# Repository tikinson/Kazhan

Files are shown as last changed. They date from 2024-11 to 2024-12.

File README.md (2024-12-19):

# 🦇Kazhan🦇

projectlogo

28 Keys. MX and Choc compatible keyboard with CH552T controller. This is the next logical step after my experimental keyboard [ToadsTempest](https://github.com/tikinson/ToadsTempest).

## Idea

Kazhan (Кажан) is derived from the Ukrainian word meaning "bat".
As a fan of ZilpZalp/Hummingbird projects i decided make something with same layout but more personalized. Same but different.

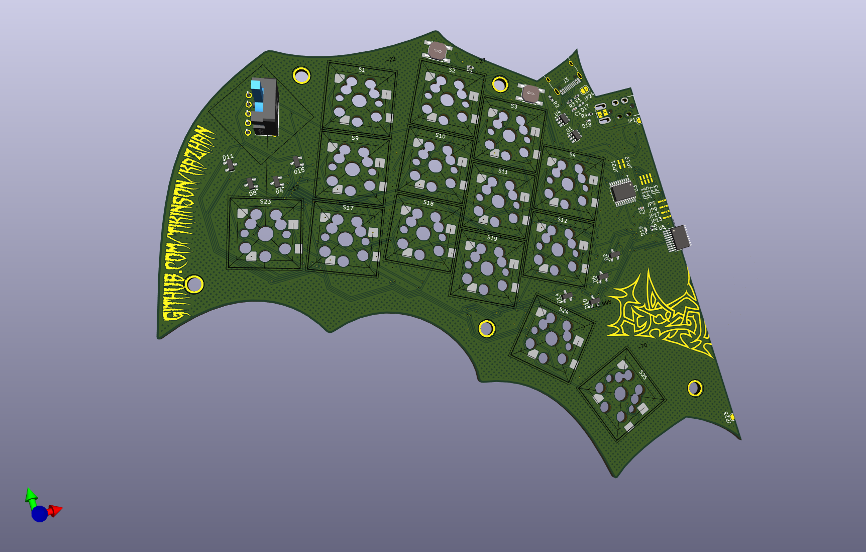
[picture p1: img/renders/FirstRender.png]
first_render


## What this project is and what it is not

### Goals:
- A pet project of a keyboard as an act of absolute self-expression.
- Flexibility and experiments over (and maybe in some case against) minimalistic design approach.
- Testing interesting "non - conventional" switches as extra keys.
- Testing things that i don't saw (yet?) in another keyboard PCB designs.

### Non-goals:
- Creation of another variant of the Corne (I like Corne btw, that was my first love in this hobby).
- Design with a definite assembly variant.
- Go through the steps in the keyboard design that I have already tried.

## Features

- Mirrored design of PCB to provide split and unibody functionality in one design.
- Alpsalpine limit switches (SW1, SW2 on schematics) as additional switches. I accidentaly understood, that MX keycap kinda fits on them (with 45 dergee rotation), so i would give them a try.
- Wired USB-C (USB 2.0) connection.
- Designed for usage with [really affordable chip](https://www.lcsc.com/product-detail/USB-ICs_WCH-Jiangsu-Qin-Heng-CH552T_C111367.html) and [F.A.K.](https://github.com/semickolon/fak?tab=readme-ov-file) firmware.
- Japanese (duplex) matrix of keys and diodes for them: first of all, it's way more easy to solder one dual diode instead of two regular, because you will never put this part with wrond polarity. And also because of type of key matrix, there is two types of dual diodes: with common anode and common cathode.

## Layout

## BOM

Opening local copy of [ibom.html](./bom/ibom.html) could save some times while soldering.

| Reference | Value | Footprint | Qty | LCSC |
|---|---|---|-----|---|
| C1, C2 | 100nF | Capacitor_SMD:C_0402_1005Metric_Pad0.74x0.62mm_HandSolder  | 2 | C1525 |
| D1, D4, D5, D8, D9, D11, D13, D15 | BAS70-06-CAnode | Package_TO_SOT_SMD:SOT-23 | 8 | C8651 |
| D2, D3, D6, D7, D10, D12, D14, D16 | BAS70-05-CCatode  | Package_TO_SOT_SMD:SOT-23 | 8 | C34489 |
| D17 | PMEG2010EA | Diode_SMD:D_0402_1005Metric_Pad0.77x0.64mm_HandSolder | 1 | C2837790  |
| D18, D19 | PWR LED | LED_SMD:LED_0402_1005Metric | 2 | C130724 |
| F1 | 500mA | Fuse:Fuse_0402_1005Metric_Pad0.77x0.64mm_HandSolder | 1 | C210357 |
| J3 | USB_C_Receptacle_USB2.0 | Connector_USB:USB_C_Receptacle_HRO_TYPE-C-31-M-12 | 1 | C2765186  |
| R1, R6 | 10k | Resistor_SMD:R_0402_1005Metric_Pad0.72x0.64mm_HandSolder | 2 | C25744 |
| R2, R3 | 5.1k | Resistor_SMD:R_0402_1005Metric_Pad0.72x0.64mm_HandSolder | 2 | C25905 |
| R4, R5 | 1k | Resistor_SMD:R_0402_1005Metric | 2 | C11702 |
| SW1, SW2 | ~ | MyFootprintsCollection:SW-TH_SSCF110100 | 2 | C470322 |
| SW4, SW6 | RESET | KEY-SMD_4P-L4.8-W4.8-P3.70-LS6.4-TL | 2 | C2888968  |
| S1–S28 | Keyswitch | SW_Hotswap_Kailh_Choc_MX_1.00u_One_Sided | 28  | |
| U1, U4 | USBLC6-2SC6 | Package_TO_SOT_SMD:SOT-23-6 | 2 | C2687116  |
| U2, U3, U5 | CH552T | -- mixed footprints -- | 3 | C111367 |

#### Note: S1-S28 - is footprints for switches. You can choose between MX or Kailh Choc switches (or both if you like experiments) and solder hotswaps accordingly.

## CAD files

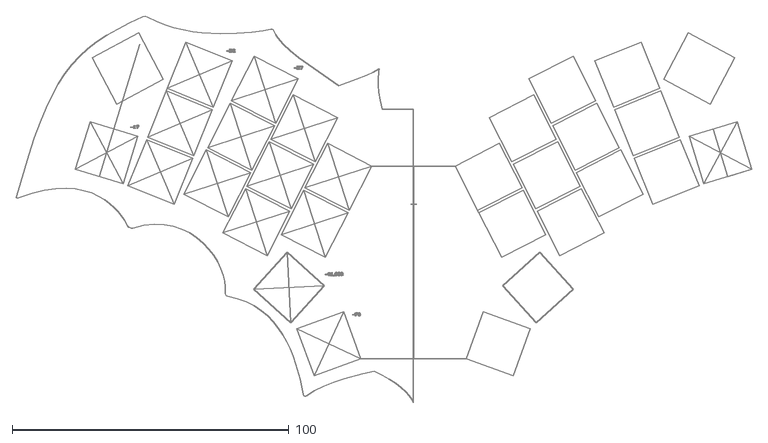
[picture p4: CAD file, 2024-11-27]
img/kazhanSecond.dxf
265.8 x 139.6

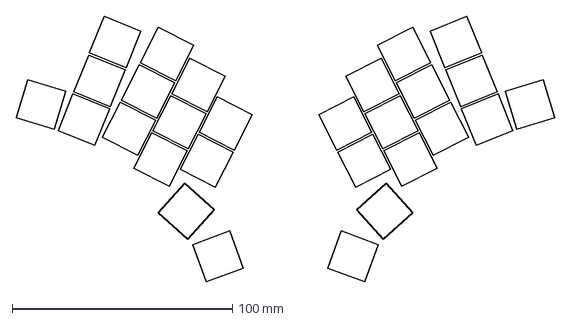
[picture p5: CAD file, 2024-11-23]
img/renders/demo.dxf
244.5 x 120.6 mm

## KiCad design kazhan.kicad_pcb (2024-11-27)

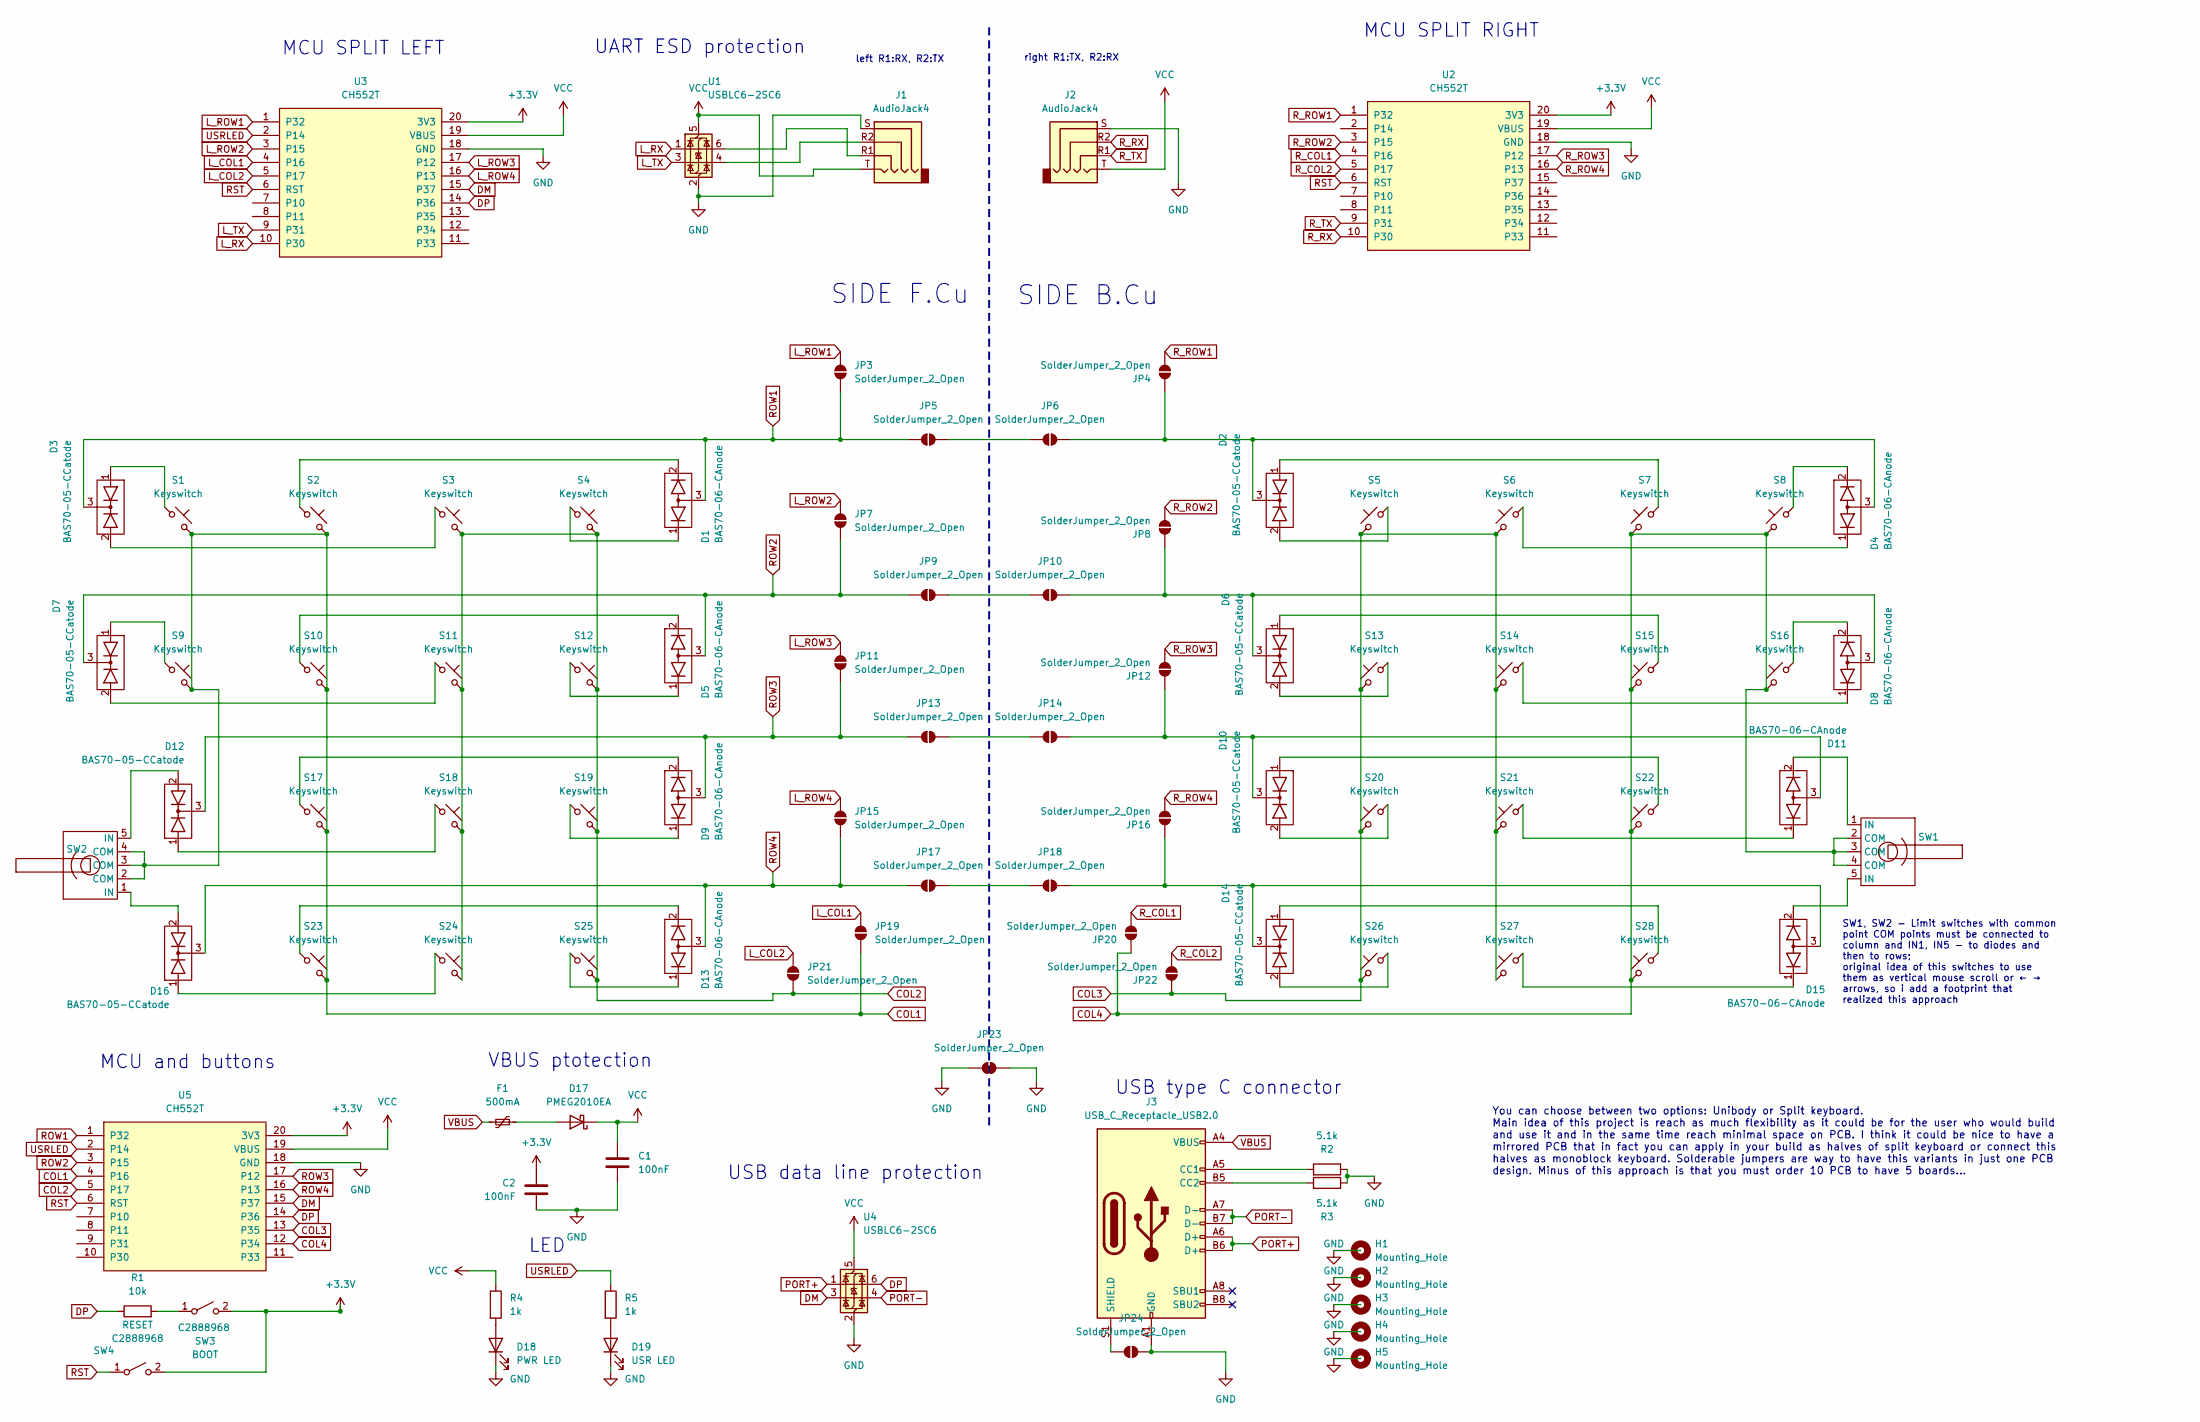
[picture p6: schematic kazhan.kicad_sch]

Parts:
C1, C2: 100nF; C_0402_1005Metric_Pad0.74x0.62mm_HandSolder; LCSC C1525
D1, D4, D5, D8, D9, D11, D13, D15: BAS70-06-CAnode; SOT-23
D2, D3, D6, D7, D10, D12, D14, D16: BAS70-05-CCatode; SOT-23
D17: PMEG2010EA; D_0402_1005Metric_Pad0.77x0.64mm_HandSolder; LCSC C2837790
D18: PWR LED; LED_0402_1005Metric; LCSC C130724
D19: USR LED; LED_0402_1005Metric; LCSC C130724
F1: 500mA; Fuse_0402_1005Metric_Pad0.77x0.64mm_HandSolder; LCSC C210357
H1, H2, H3, H4, H5: Mounting_Hole; MountingHole_3.5mmX4.5mm_Pad
J1: AudioJack4; PJ-320A-REVERSIBLE-F.Cu-placing
J2: AudioJack4; PJ-320A-REVERSIBLE-B.Cu-placing
J3: USB_C_Receptacle_USB2.0; USB_C_Receptacle_HRO_TYPE-C-31-M-12; JLCPCB_CORRECTION 0; -1.35; 0
JP3, JP4, JP7, JP8, JP11, JP12, JP15, JP16, JP19, JP20, JP21, JP22, JP24: SolderJumper_2_Open; SolderJumper-2_P1.3mm_Open_RoundedPad1.0x1.5mm
JP5, JP9, JP13, JP17: SolderJumper_2_Open; SolderJumper-EdgeCut-F.Cu-Placing
JP6, JP10, JP14, JP18: SolderJumper_2_Open; SolderJumper-EdgeCut-B.Cu-Placing
JP23: SolderJumper_2_Open; SolderJumper-F.Cu-B.Cu
R1: 10k; R_0402_1005Metric_Pad0.72x0.64mm_HandSolder; LCSC C25744
R2, R3: 5.1k; R_0402_1005Metric_Pad0.72x0.64mm_HandSolder; LCSC C25905
R4, R5: 1k; R_0402_1005Metric; LCSC C11702
S1, S2, S3, S4, S5, S6, S7, S8, S9, S10, S11, S12, S13, S14, S15, S16, S17, S18, S19, S20, S21, S22, S23, S24, S25, S26, S27, S28: Keyswitch; SW_Hotswap_Kailh_Choc_MX_1.00u_One_Sided
SW1, SW2: SW-TH_SSCF110100
SW3: BOOT; KEY-SMD_4P-L4.8-W4.8-P3.70-LS6.4-TL; LCSC C115357
SW4: RESET; KEY-SMD_4P-L4.8-W4.8-P3.70-LS6.4-TL; LCSC C115357
U1, U4: USBLC6-2SC6; SOT-23-6; JLCPCB_CORRECTION 0; 0; 270
U2, U3: CH552T; TSSOP-20_4.4x6.5mm_P0.65mm; LCSC C111367
U5: CH552T; TSSOP-20_4.4x6.5mm_P0.65mm-REVERSIBLE; LCSC C111367

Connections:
+3.3V: C2.1, SW3.2 (B), SW4.2 (B), U2.20 (3V3), U3.20 (3V3), U5.20 (3V3)
COL1: JP19.1 (A), S1.2, S2.2, S9.2, S10.2, S17.2, S23.2, SW2.2 (COM), SW2.3 (COM), SW2.4 (COM), U5.4 (P16)
COL2: JP21.1 (A), S3.2, S4.2, S11.2, S12.2, S18.2, S19.2, S24.2, S25.2, U5.5 (P17)
COL3: JP22.2 (B), S5.2, S6.2, S13.2, S14.2, S20.2, S21.2, S26.2, S27.2, U5.13 (P35)
COL4: JP20.2 (B), S7.2, S8.2, S15.2, S16.2, S22.2, S28.2, SW1.2 (COM), SW1.3 (COM), SW1.4 (COM), U5.12 (P34)
DM: U3.15 (P37), U4.3 (I/O2), U5.15 (P37)
DP: R1.1, U3.14 (P36), U4.6 (I/O1), U5.14 (P36)
GND: C1.2, C2.2, D18.1 (K), D19.1 (K), J1.S, J2.S, J3.A1 (GND), J3.A12 (GND), J3.B1 (GND), J3.B12 (GND), JP23.1 (A), JP23.2 (B), JP24.2 (B), R2.1, R3.1, U1.2 (GND), U2.18 (GND), U3.18 (GND), U4.2 (GND), U5.18 (GND); also elsewhere on the board
L_COL1: JP19.2 (B), U3.4 (P16)
L_COL2: JP21.2 (B), U3.5 (P17)
L_ROW1: JP3.2 (B), U3.1 (P32)
L_ROW2: JP7.1 (A), U3.3 (P15)
L_ROW3: JP11.1 (A), U3.17 (P12)
L_ROW4: JP15.1 (A), U3.16 (P13)
L_RX: U1.1 (I/O1), U3.10 (P30)
L_TX: U1.3 (I/O2), U3.9 (P31)
unnamed: D1.1 (A), S4.1
unnamed: D1.2 (A), S2.1
unnamed: D2.1 (A), S7.1
unnamed: D2.2 (A), S5.1
unnamed: D2.3 (K), D4.3 (K), JP4.1 (A), JP6.2 (B)
unnamed: D3.1 (A), S1.1
unnamed: D3.2 (A), S3.1
unnamed: D4.1 (A), S6.1
unnamed: D4.2 (A), S8.1
unnamed: D5.1 (A), S12.1
unnamed: D5.2 (A), S10.1
unnamed: D6.1 (A), S15.1
unnamed: D6.2 (A), S13.1
unnamed: D6.3 (K), D8.3 (K), JP8.1 (A), JP10.2 (B)
unnamed: D7.1 (A), S9.1
unnamed: D7.2 (A), S11.1
unnamed: D8.1 (A), S14.1
unnamed: D8.2 (A), S16.1
unnamed: D9.1 (A), S19.1
unnamed: D9.2 (A), S17.1
unnamed: D10.1 (A), S22.1
unnamed: D10.2 (A), S20.1
unnamed: D10.3 (K), D11.3 (K), JP12.1 (A), JP14.2 (B)
unnamed: D11.1 (A), S21.1
unnamed: D11.2 (A), SW1.1 (IN)
unnamed: D12.1 (A), S18.1
unnamed: D12.2 (A), SW2.5 (IN)
unnamed: D13.1 (A), S25.1
unnamed: D13.2 (A), S23.1
unnamed: D14.1 (A), S28.1
unnamed: D14.2 (A), S26.1
unnamed: D14.3 (K), D15.3 (K), JP16.2 (B), JP18.2 (B)
unnamed: D15.1 (A), S27.1
unnamed: D15.2 (A), SW1.5 (IN)
unnamed: D16.1 (A), S24.1
unnamed: D16.2 (A), SW2.1 (IN)
unnamed: D17.2 (A), F1.1
unnamed: D18.2 (A), R4.2
unnamed: D19.2 (A), R5.2
unnamed: J1.R1, U1.6 (I/O1)
unnamed: J1.R2, U1.4 (I/O2)
unnamed: J3.A5 (CC1), R2.2
unnamed: J3.B5 (CC2), R3.2
unnamed: J3.S1 (SHIELD), JP24.1 (A)
unnamed: JP5.2 (B), JP6.1 (A)
unnamed: JP9.2 (B), JP10.1 (A)
unnamed: JP13.2 (B), JP14.1 (A)
unnamed: JP17.2 (B), JP18.1 (A)
unnamed: R1.2, SW3.1 (A)
PORT+: J3.A6 (D+), J3.B6 (D+), U4.1 (I/O1)
PORT-: J3.A7 (D-), J3.B7 (D-), U4.4 (I/O2)
ROW1: D1.3 (K), D3.3 (K), JP3.1 (A), JP5.1 (A), U5.1 (P32)
ROW2: D5.3 (K), D7.3 (K), JP7.2 (B), JP9.1 (A), U5.3 (P15)
ROW3: D9.3 (K), D12.3 (K), JP11.2 (B), JP13.1 (A), U5.17 (P12)
ROW4: D13.3 (K), D16.3 (K), JP15.2 (B), JP17.1 (A), U5.16 (P13)
RST: SW4.1 (A), U2.6 (RST), U3.6 (RST), U5.6 (RST)
R_COL1: JP20.1 (A), U2.4 (P16)
R_COL2: JP22.1 (A), U2.5 (P17)
R_ROW1: JP4.2 (B), U2.1 (P32)
R_ROW2: JP8.2 (B), U2.3 (P15)
R_ROW3: JP12.2 (B), U2.17 (P12)
R_ROW4: JP16.1 (A), U2.16 (P13)
R_RX: J2.R2, U2.10 (P30)
R_TX: J2.R1, U2.9 (P31)
USRLED: R5.1, U3.2 (P14), U5.2 (P14)
VBUS: F1.2, J3.A4 (VBUS), J3.A9 (VBUS), J3.B4 (VBUS), J3.B9 (VBUS)
VCC: C1.1, D17.1 (K), J1.T, J2.T, R4.1, U1.5 (VBUS), U2.19 (VBUS), U3.19 (VBUS), U4.5 (VBUS), U5.19 (VBUS)

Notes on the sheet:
SW1, SW2 - Limit switches with common point COM points must be connected to column and IN1, IN5 - to diodes and then to rows; original idea of this switches to use them as vertical mouse scroll or ← → arrows, so i add a footprint that realized this approach
You can choose between two options: Unibody or Split keyboard. Main idea of this project is reach as much flexibility as it could be for the user who would build and use it and in the same time reach minimal space on PCB. I think it could be nice to have a mirrored PCB that in fact you can apply in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
MCU and buttons
right R1:TX, R2:RX
USB type C connector
MCU SPLIT LEFT
SIDE B.Cu
USB data line protection
left R1:RX, R2:TX
MCU SPLIT RIGHT
LED
UART ESD protection
VBUS ptotection
SIDE F.Cu

Board: 2 copper layers, 96 parts (24 on the bottom side), 83 nets, no tracks yet.

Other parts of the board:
JP1, JP2: SolderJumper_2_Open; SolderJumper-2_P1.3mm_Open_RoundedPad1.0x1.5mm

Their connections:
GND: JP1.2 (B), JP2.2 (B); also elsewhere on the board

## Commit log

2024-11-23 work with readme
    [demo.dxf]
2024-11-27 outline and placing started
    [kazhan.kicad_pcb, kazhan.kicad_sch, kazhanSecond.dxf]
2024-12-01 all except matrix is routed
    [kazhan.kicad_sch, kazhan_oldCopy.kicad_pcb]
2024-12-19 upd readme
    [kazhan.kicad_sch]
